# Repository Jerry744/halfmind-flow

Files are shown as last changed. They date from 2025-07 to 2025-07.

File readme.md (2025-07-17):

# Halfmind Flow

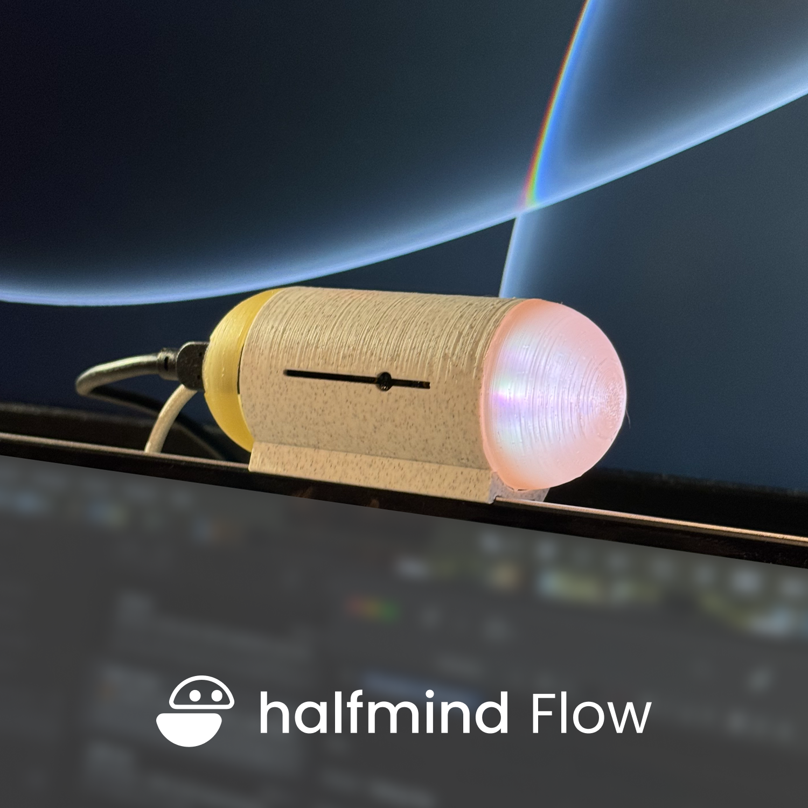
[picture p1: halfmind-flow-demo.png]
Halfmind Flow Demo

*Demo: Halfmind Flow system in action*

**Halfmind Flow** explores how radar sensing can support focus at work by detecting presence and breathing patterns to gently intervene when attention drifts.  
This project is part of my Master’s graduation project in the Integrated Product Design program at TU Delft.

## Overview

Halfmind Flow uses a 60 GHz millimeter-wave radar to sense whether someone is at their desk and monitors subtle breathing patterns. It calculates breathing rate variability (BRV) to infer focus and restlessness. When signs of distraction appear, ambient music and light adjust to help restore flow.

## Key Features

- Real-time presence and breathing detection via radar  
- Rule-based classification of work states using BRV  
- Generative music in Max/MSP to support focus  
- Ambient lighting driven by ESP32 with 7 LEDs to visualize breath depth or provide subtle nudges  
- Debug visualizations in PyQT5

## How It Works

1. Radar captures raw signals of presence and chest movements.  
2. Signal processing (FFT and filtering) extracts breathing features.  
3. A rule-based approach uses BRV to estimate current focus state.  
4. Music and lights adjust in response to support sustained attention.

## Tech Stack

- **Hardware:** Infineon BGT60TR13C radar module, ESP32 LED controller  
- **Software:** Python for signal processing, Max/MSP for music generation, PyQT5 for debugging  
- **Future Work:** Integration with Home Assistant and other ambient devices

## Roadmap

- [ ] Refine BRV detection and link to focus/anxiety states  
- [ ] Improve generative music logic  
- [ ] Expand lighting intervention scenarios  
- [ ] Test in real-world work setups and multi-user contexts

## Acknowledgements

- Radar signal processing inspired by work from Prof. Mohammad Alaee-Kerahroodi ([radarmimo GitHub](https://github.com/radarmimo/Download-Center)) and the Infineon Radar SDK.
- Generative music system references UndulaeMusic ([Patreon](https://www.patreon.com/UndulaeMusic)) and other open-source Max/MSP projects.
- Special thanks to my mentors and peers at TU Delft for their valuable guidance and feedback.

## License

This project is released under the XXX License. See [`LICENSE`](./LICENSE) for details.

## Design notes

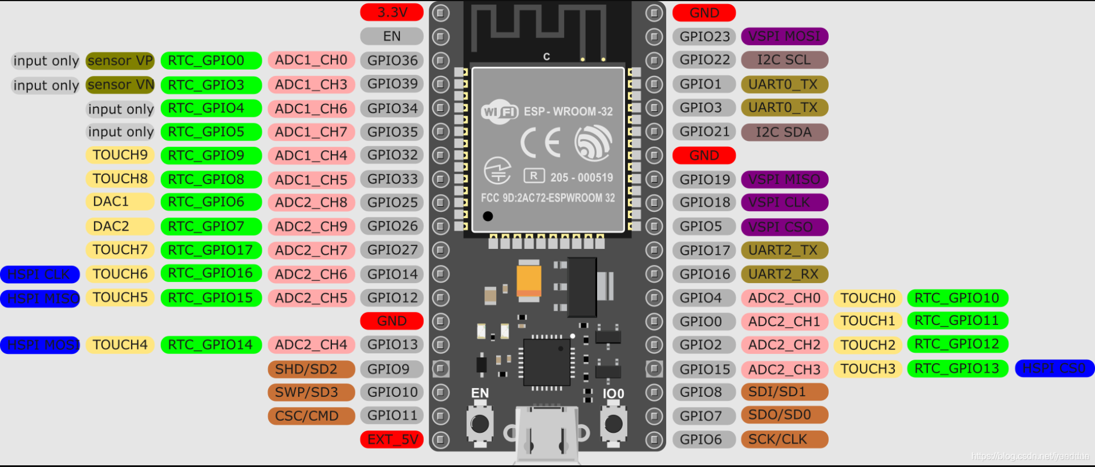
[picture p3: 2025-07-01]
arduino_esp32/esp32_layout.png

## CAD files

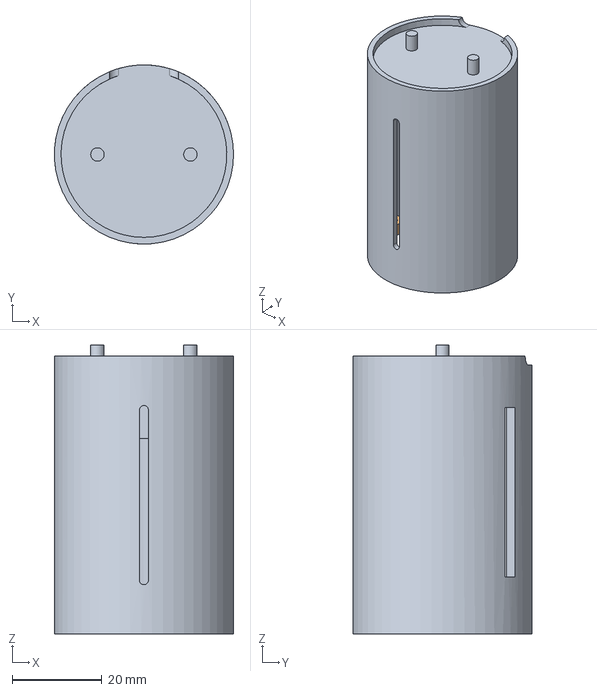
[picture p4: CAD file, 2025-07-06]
capsule/capsule_structure_assembly v11.step
40.0 x 40.0 x 64.5 mm

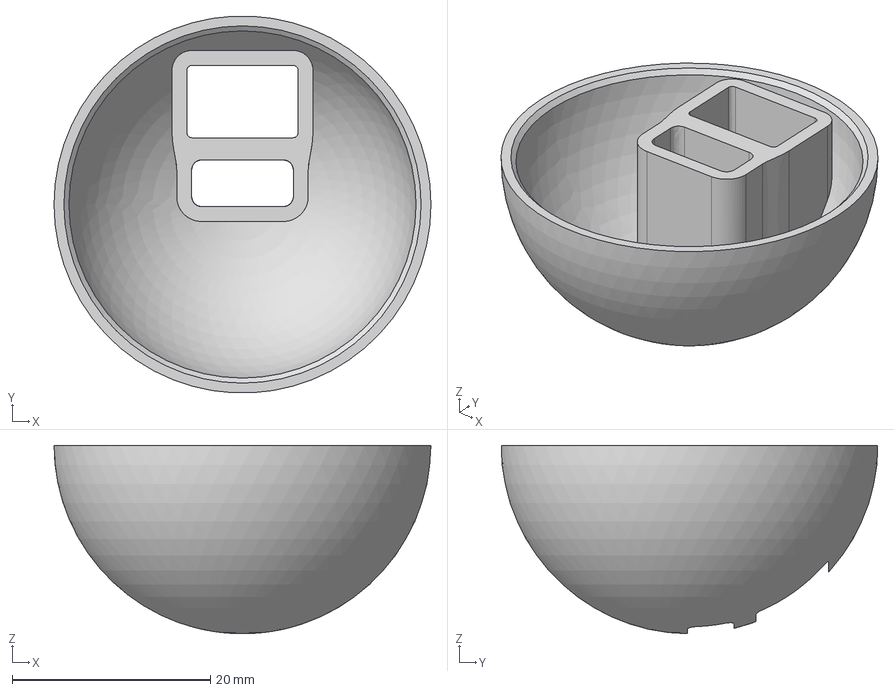
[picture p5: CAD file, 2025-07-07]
capsule/Hat_cable.step
38.0 x 37.9 x 19.0 mm

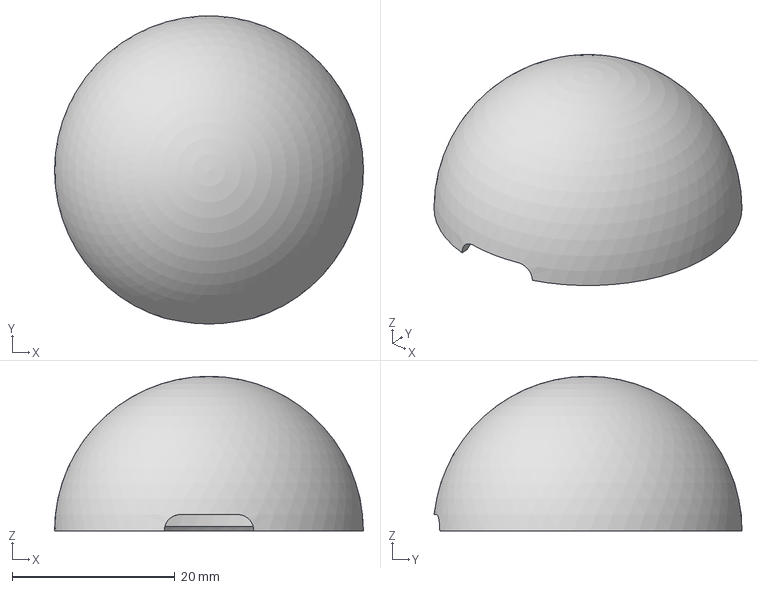
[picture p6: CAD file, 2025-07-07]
capsule/Hat_LED.step
38.0 x 37.9 x 19.0 mm

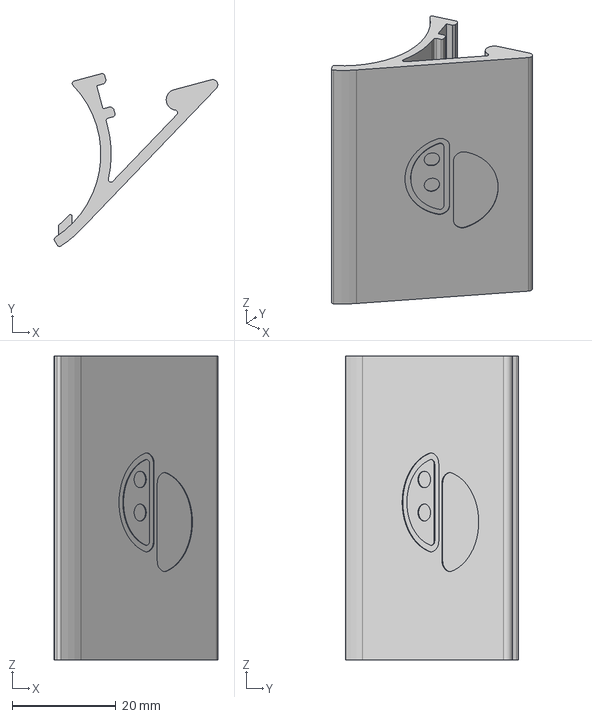
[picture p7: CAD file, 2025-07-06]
capsule/housing_stand.step
31.5 x 33.3 x 58.5 mm

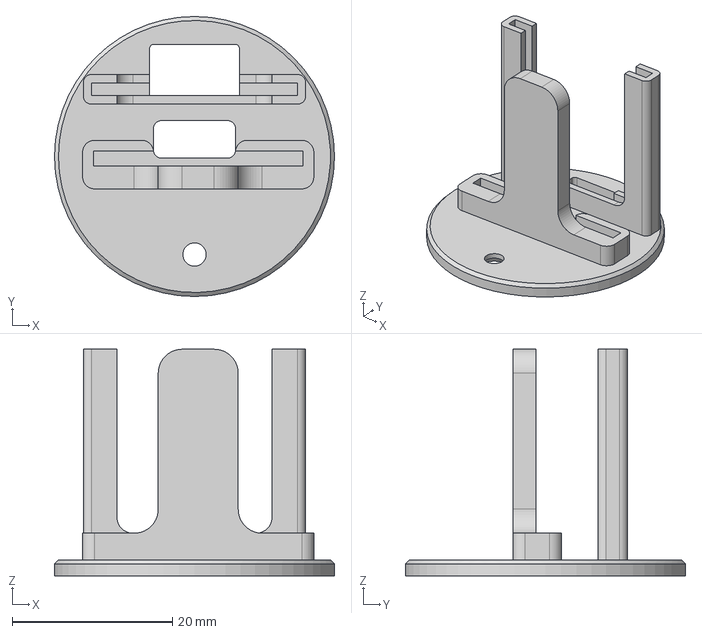
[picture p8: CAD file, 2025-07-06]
capsule/base v2.step
35.0 x 35.0 x 28.3 mm

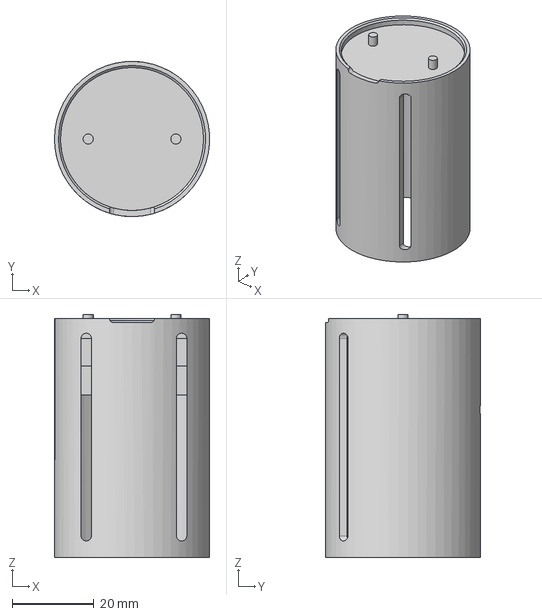
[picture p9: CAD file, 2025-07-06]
capsule/Shellv2.step
38.0 x 38.0 x 59.5 mm

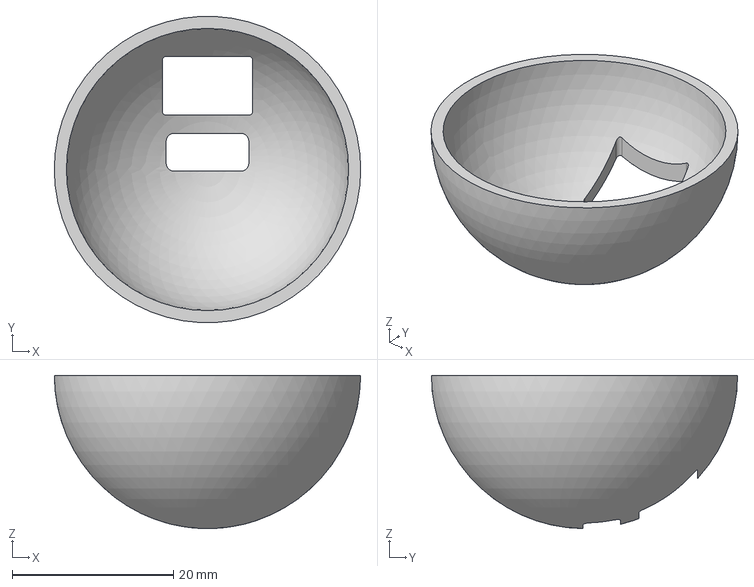
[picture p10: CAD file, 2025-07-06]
capsule/hat2.step
38.0 x 37.9 x 19.0 mm

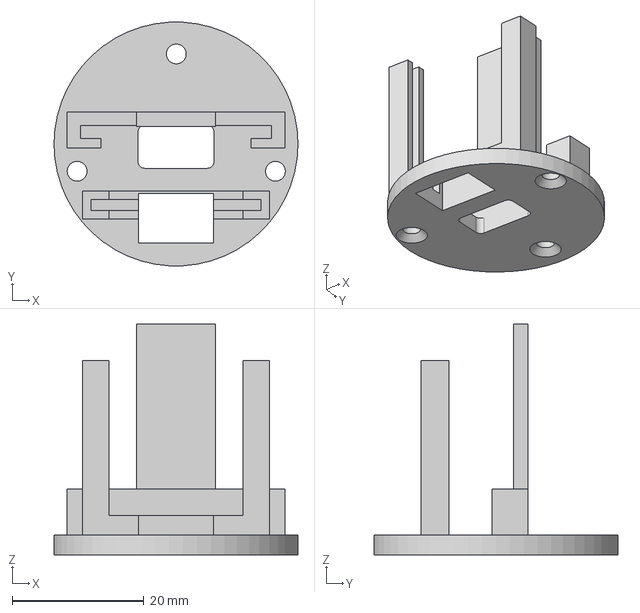
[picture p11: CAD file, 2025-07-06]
capsule/structure_base v5.step
37.0 x 36.9 x 35.0 mm

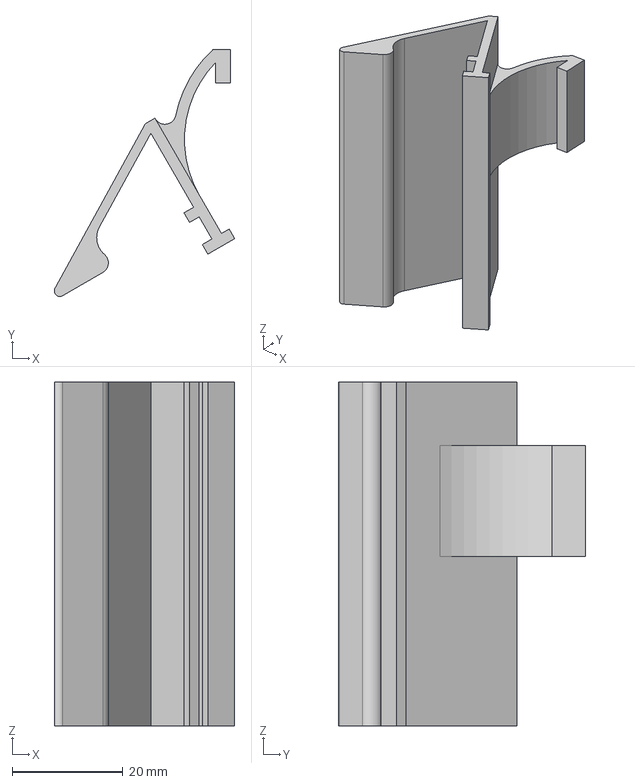
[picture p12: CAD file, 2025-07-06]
capsule/housing_holder.step
32.5 x 44.5 x 62.0 mm

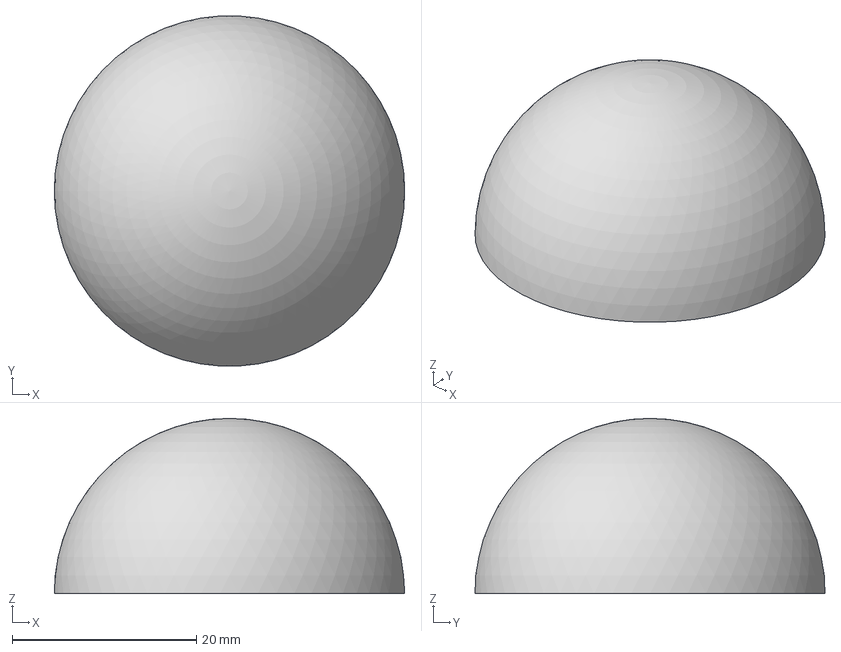
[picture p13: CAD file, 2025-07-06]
capsule/hat1.step
38.0 x 37.9 x 19.0 mm

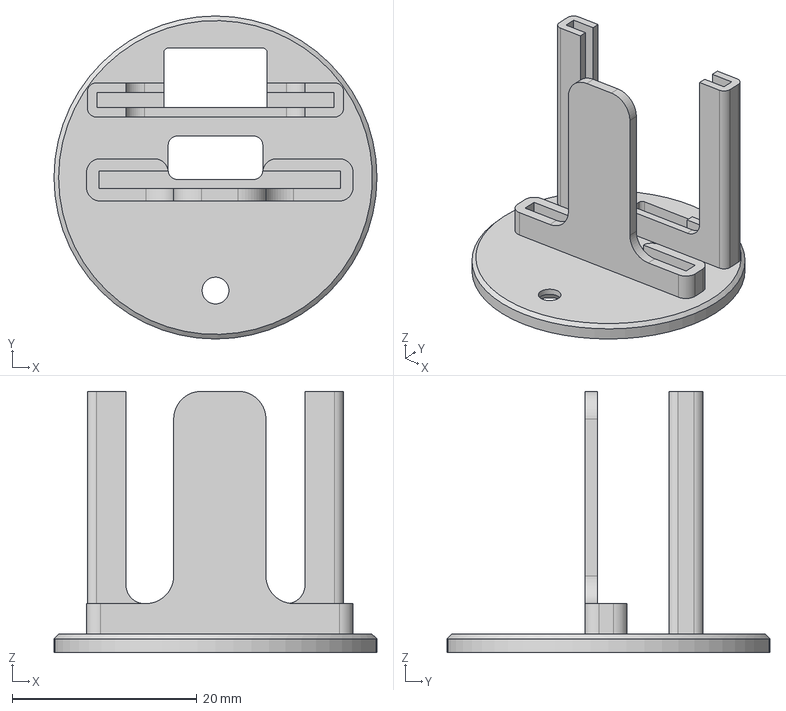
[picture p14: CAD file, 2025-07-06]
capsule/capsule-thinesp v2.step
35.0 x 35.0 x 28.3 mm

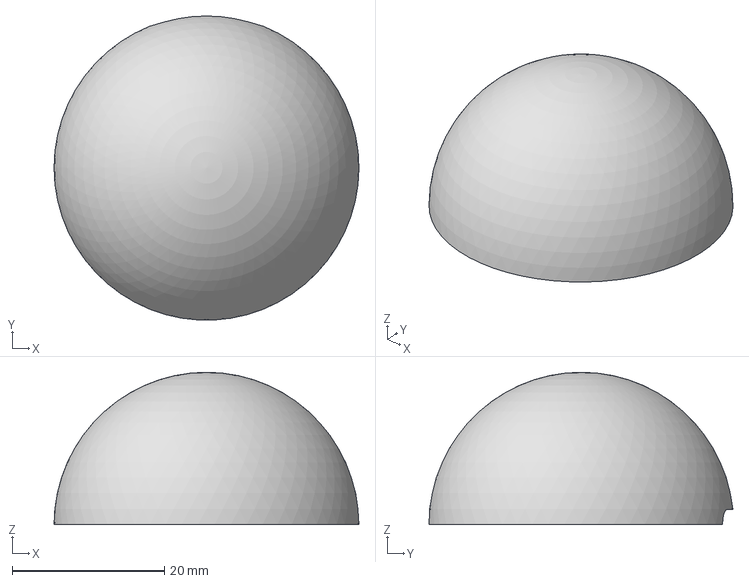
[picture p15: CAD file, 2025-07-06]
capsule/LED_Hat.step
40.0 x 39.9 x 20.0 mm

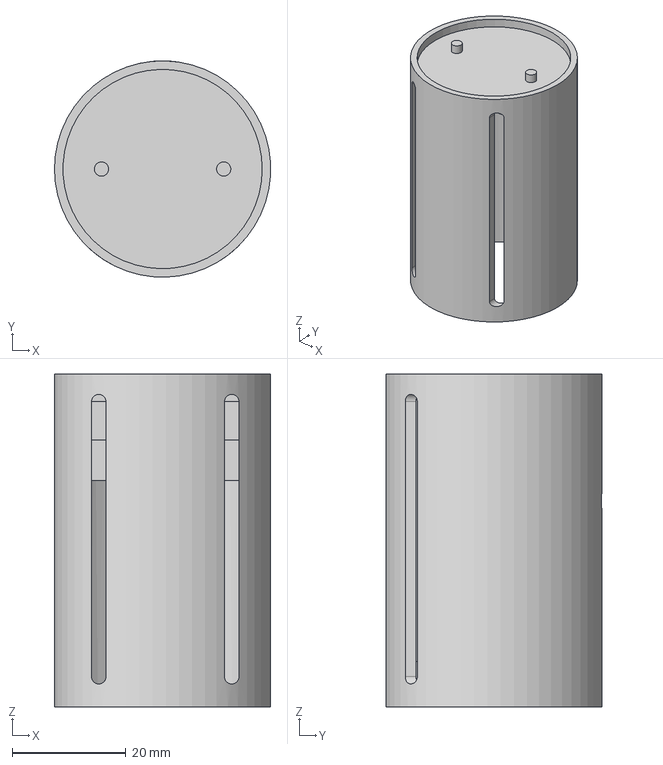
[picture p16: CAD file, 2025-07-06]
capsule/Shell.step
38.0 x 38.0 x 58.5 mm

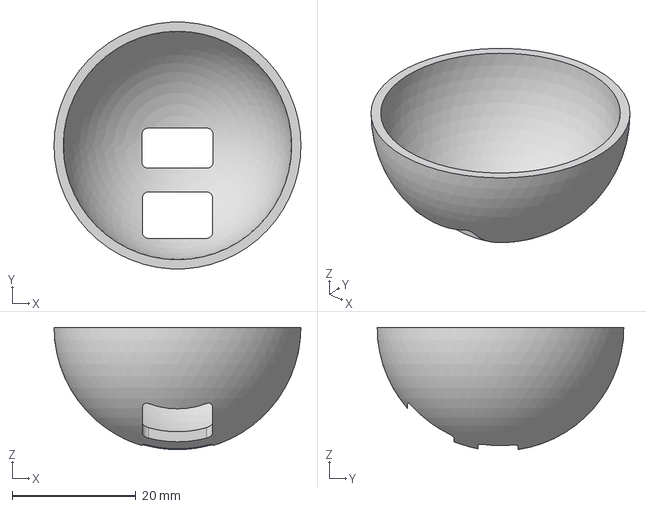
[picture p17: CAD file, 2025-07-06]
capsule/Cable_Hat.step
40.0 x 39.9 x 19.8 mm

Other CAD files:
capsule/Component4.step
capsule/structure_hat_v3 v1(Mirror).step
capsule/structure_v1_shell.stp
capsule/structure_hat_v3.stp
capsule/capsule_structure_assembly v6.step
capsule/capsule_structure_assembly v8.step
capsule/esp32.stp
capsule/led.stp
capsule/radar.stp
capsule/structure_base v2.step
capsule/structure_base v4.step
capsule/structure_base.step
capsule/structure_base_v2.stp
capsule/structure_base_v3.stp
capsule/structure_shell_v2.stp
capsule/structure_shell_v3.stp
capsule/structure_v1.stp
capsule/structure_v1_base.stp
capsule/structure_v1_hat.stp

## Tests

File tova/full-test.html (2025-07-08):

# T.O.V.A.

## Test of Variables of Attention

In the following task, you will be presented a series of stimuli consisting of a large white square with a small black square inside it.

On some trials, the small square will be near the top of the white square. These are target stimuli.

On other trials, the small square will be near the bottom. These are NOT target stimuli.

Continue to see the stimuli.

Continue

## Instructions

Your task is to decide if each stimulus is a target or non-target.

Press the space bar as quickly as you can whenever you see a target (top square).

Do nothing when you see a non-target (bottom square).

The task lasts approximately 23 minutes, so you must concentrate to perform well. First you will have 3 minutes to practice.

View Sample Stimuli

## 🎯 Target Stimulus Example

This is a Target stimulus.
When you see the small black square at the TOP of the white background,
press the SPACEBAR as quickly as possible.

Next: Non-Target Example

## ❌ Non-Target Stimulus Example

This is a Non-target stimulus.
When you see the small black square at the BOTTOM of the white background,
DO NOT PRESS ANY KEY - simply wait for the next stimulus.

Start Practice

ERROR

## Practice Complete

You have completed practice. The task will now begin.

Continue (Space)

## Practice Finished

You have successfully completed the practice session.

Press SPACEBAR to begin TOVA test.

Begin TOVA Test

# Thank you!

The test is complete.

Download Raw Data Download Summary Data

Start New Test Return to Main Page

### Subject Information

Subject Name:

Group ID:

Session ID:

Start Test

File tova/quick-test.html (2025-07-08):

Debug Info:

Phase: -

Block: -

Trial: -

Type: -

Last RT: -ms

Total Trials: -

Quick Controls:

Skip to Test Speed Up (100ms SOA) Normal Speed Show Stats Download Data

# T.O.V.A. Quick Test Mode

This is a debug/development version with shortened trials for testing.

Changes from full version:

- Practice: 6 trials (instead of 50)
- Each test block: 20 trials (instead of 162)
- Debug panel shows real-time info
- Quick controls for testing

Start Quick Test Full Test

# Quick Test Complete!

Download Data Restart

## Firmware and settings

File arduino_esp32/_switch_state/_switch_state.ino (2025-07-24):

#include <Adafruit_NeoPixel.h>
#include <WiFi.h>
#include <WiFiUdp.h>
#include <OSCMessage.h>

#define LED_PIN     12      // D12
#define NUM_LEDS    7
#define TOUCH_PIN   T0     // D4 (GPIO4, touch-capable)
#define BREATH_CYCLE_LENGTH 4.0  // Half breathing cycle in seconds

// WiFi settings
// const char* ssid = "TP-Link_CF74";
// const char* password = "81541027";

const char* ssid = "TP-Link_122D";
const char* password = "05997343";

const char* ssid_test = "TP-Link_DDFE";
const char* password_test = "10450215";
// OSC settings
WiFiUDP Udp;
const unsigned int localPort = 8888;  // Local port to listen on
const char* oscStatusAddress = "/status";        // OSC address for state control
const char* oscBreathingAddress = "/breathingrate"; // OSC address for breathing rate
const char* oscConfigAddress = "/config";            // OSC address for configuration
const char* oscAmplitudeAddress = "/amplitude";        // OSC address for amplitude control

// Designated IP address for OSC messages (change this to your sender's IP)
IPAddress designatedIP(192, 168, 31, 128);  // Change to your designated IP address
bool enableIPFiltering = false;  // Set to false to accept from any IP

// Dynamic breathing rate control
float currentBreathingRate = BREATH_CYCLE_LENGTH;  // Current breathing rate in seconds

// Global variables for breathing effect
float breathingBrightness = 0;
bool breathingIncreasing = true; // true = brightening, false = dimming
uint32_t breathingColor = 0;     // Set this to strip.Color(r, g, b) before use

// New global variable to store amplitude value
float breathAmplitude = 0; // 0-100, usually max 40

Adafruit_NeoPixel strip(NUM_LEDS, LED_PIN, NEO_GRB + NEO_KHZ800);

// 状态定义
enum {
  SETUP_TEST = 0,
  STATUS_0,   // nobody
  STATUS_1,   // user appear
  STATUS_2,   // user working
  STATUS_3,   // out of focus
  STATUS_4,   // time up
  STATUS_5    // user leave
};
int state = SETUP_TEST;
unsigned long stateStartTime = 0;
bool waitingForTimeout = false;
unsigned long lastTouchTime = 0;

// Helper function to connect to WiFi with timeout (returns true if connected, false if timeout)
bool connectToWiFiWithTimeout(const char* ssid, const char* password, unsigned long timeoutMs) {
  // Turn all LEDs yellow while connecting
  for (int i = 0; i < NUM_LEDS; i++) {
    strip.setPixelColor(i, strip.Color(30, 30, 0)); // Yellow
  }
  strip.show();

  WiFi.begin(ssid, password);
  Serial.print("Connecting to WiFi");
  unsigned long startAttemptTime = millis();
  while (WiFi.status() != WL_CONNECTED && millis() - startAttemptTime < timeoutMs) {
    delay(500);
    Serial.print(".");
  }
  Serial.println();

  bool connected = WiFi.status() == WL_CONNECTED;
  if (connected) {
    // Show green for 2 seconds
    for (int i = 0; i < NUM_LEDS; i++) {
      strip.setPixelColor(i, strip.Color(0, 30, 0)); // Green
    }
    strip.show();
    delay(2000);
  } else {
    // Show red for 2 seconds
    for (int i = 0; i < NUM_LEDS; i++) {
      strip.setPixelColor(i, strip.Color(30, 0, 0)); // Red
    }
    strip.show();
    delay(2000);
  }
  // Clear LEDs after feedback
  strip.clear();
  strip.show();
  return connected;
}

void setup() {
  Serial.begin(115200);
  Serial.println("Starting LED State Controller with OSC...");
  
  // Initialize LED strip
  strip.begin();
  strip.show();

  // Connect to WiFi with 30s timeout
  bool wifiConnected = connectToWiFiWithTimeout(ssid, password, 8000);
  if (!wifiConnected) {
    Serial.println("Primary WiFi failed. Trying backup WiFi...");
    wifiConnected = connectToWiFiWithTimeout(ssid_test, password_test, 8000);
  }
  if (wifiConnected) {
    Serial.print("Connected! IP address: ");
    Serial.println(WiFi.localIP());
    // Start UDP
    Udp.begin(localPort);
    Serial.print("OSC listening on port: ");
    Serial.println(localPort);
    Serial.println("OSC addresses: /status, /breathingrate, /config");
    // Display OSC security settings
    if (enableIPFiltering) {
      Serial.print("OSC IP filtering ENABLED - Only accepting messages from: ");
      Serial.println(designatedIP);
    } else {
      Serial.println("OSC IP filtering DISABLED - Accepting messages from any IP");
    }
  } else {
    Serial.println("WiFi connection failed after 8 seconds (both networks). Skipping network setup.");
  }
  
  state = STATUS_0;
  Serial.println("Setup complete. Entering STATUS_0 (nobody)");
}

void loop() {
  handleTouch();
  handleOSC();  // Handle incoming OSC messages

  unsigned long now = millis();
  switch (state) {
    case STATUS_0: // nobody, breathing orange
      orangeLow();
      break;
    case STATUS_1: // user appear, use amplitude-based orange breath
      orangeBreathWithAmplitude(breathAmplitude);
      break;
    case STATUS_2: // user working, breathing orange
      orangeBreath();
      break;
    case STATUS_3: // out of focus, blink once, then STATUS_2
      blinkOnce();
      break;
    case STATUS_4: // time up, rainbow, then STATUS_5
      rainbowCycle(5);
      state = STATUS_5;
      break;
    case STATUS_5: // user leave, blink red 5s, then STATUS_0
      redBlink5s();
      break;
  }
}

// Handle incoming OSC messages
void handleOSC() {
  OSCMessage msg;
  int size = Udp.parsePacket();
  
  if (size > 0) {
    // Get the sender's IP address
    IPAddress senderIP = Udp.remoteIP();
    
    // Check if IP filtering is enabled and if the sender is authorized
    if (enableIPFiltering && senderIP != designatedIP) {
      Serial.print("OSC message rejected from unauthorized IP: ");
      Serial.println(senderIP);
      
      // Clear the packet buffer
      while (size--) {
        Udp.read();
      }
      return;
    }
    
    // Process the message if IP is authorized or filtering is disabled
    while (size--) {
      msg.fill(Udp.read());
    }
    
    if (!msg.hasError()) {
      Serial.print("OSC message accepted from: ");
      Serial.println(senderIP);
      
      msg.route(oscStatusAddress, routeStatus);
      msg.route(oscBreathingAddress, routeBreathingRate);
      msg.route(oscConfigAddress, routeConfig);
      msg.route(oscAmplitudeAddress, routeAmplitude);
    } else {
      Serial.println("OSC message has errors");
    }
  }
}

// Route function for status OSC messages
void routeStatus(OSCMessage &msg, int addrOffset) {
  if (msg.isInt(0)) {
    int newState = msg.getInt(0);
    // Accept only 0-5 and map to STATUS_0..STATUS_5
    if (newState >= 0 && newState <= 5) {
      int oldState = state;
      state = STATUS_0 + newState;
      waitingForTimeout = false;
      Serial.print("OSC /status received! State changed from ");
      Serial.print(getStateName(oldState));
      Serial.print(" to ");
      Serial.println(getStateName(state));
    } else {
      Serial.print("Invalid state received via OSC /status: ");
      Serial.println(newState);
    }
  } else {
    Serial.println("OSC /status message received but not an integer");
  }
}

// Route function for breathing rate OSC messages
void routeBreathingRate(OSCMessage &msg, int addrOffset) {
  if (msg.isFloat(0)) {
    float newRate = msg.getFloat(0);
    
    // Validate breathing rate (0.1 to 20 seconds)
    if (newRate >= 0.1 && newRate <= 20.0) {
      float oldRate = currentBreathingRate;
      currentBreathingRate = newRate;
      
      Serial.print("OSC /breathingrate received! Breathing rate changed from ");
      Serial.print(oldRate);
      Serial.print("s to ");
      Serial.print(currentBreathingRate);
      Serial.println("s");
    } else {
      Serial.print("Invalid breathing rate received via OSC /breathingrate: ");
      Serial.println(newRate);
      Serial.println("Valid range: 0.1 to 20.0 seconds");
    }
  } else if (msg.isInt(0)) {
    // Also accept integer values
    int newRate = msg.getInt(0);
    
    if (newRate >= 1 && newRate <= 20) {
      float oldRate = currentBreathingRate;
      currentBreathingRate = (float)newRate;
      
      Serial.print("OSC /breathingrate received! Breathing rate changed from ");
      Serial.print(oldRate);
      Serial.print("s to ");
      Serial.print(currentBreathingRate);
      Serial.println("s");
    } else {
      Serial.print("Invalid breathing rate received via OSC /breathingrate: ");
      Serial.println(newRate);
      Serial.println("Valid range: 1 to 20 seconds");
    }
  } else {
    Serial.println("OSC /breathingrate message received but not a number");
  }
}

// Route function for configuration OSC messages
void routeConfig(OSCMessage &msg, int addrOffset) {
  // /config/ipfilter 0|1 - Enable/disable IP filtering
  // /config/setip a.b.c.d - Set designated IP address
  
  if (msg.match("/ipfilter", addrOffset)) {
    if (msg.isInt(0)) {
      bool newFiltering = msg.getInt(0) != 0;
      bool oldFiltering = enableIPFiltering;
      enableIPFiltering = newFiltering;
      
      Serial.print("OSC /config/ipfilter received! IP filtering changed from ");
      Serial.print(oldFiltering ? "ENABLED" : "DISABLED");
      Serial.print(" to ");
      Serial.println(enableIPFiltering ? "ENABLED" : "DISABLED");
    }
  } 
  else if (msg.match("/setip", addrOffset)) {
    if (msg.isString(0)) {
      char ipStr[16];
      msg.getString(0, ipStr, 16);
      
      // Parse IP address string (format: "192.168.1.100")
      IPAddress newIP;
      if (newIP.fromString(ipStr)) {
        IPAddress oldIP = designatedIP;
        designatedIP = newIP;
        
        Serial.print("OSC /config/setip received! Designated IP changed from ");
        Serial.print(oldIP);
        Serial.print(" to ");
        Serial.println(designatedIP);
      } else {
        Serial.print("Invalid IP address format received: ");
        Serial.println(ipStr);
      }
    }
  }
  else {
    Serial.println("Unknown config command received");
  }
}

// Route function for amplitude OSC messages
void routeAmplitude(OSCMessage &msg, int addrOffset) {
  if (msg.isFloat(0)) {
    breathAmplitude = msg.getFloat(0);
  } else if (msg.isInt(0)) {
    breathAmplitude = msg.getInt(0);
  } else {
    Serial.println("OSC /amplitude message received but not a number");
  }
  Serial.print("Received /amplitude: ");
  Serial.println(breathAmplitude);
}

// Helper function to get state name for debugging
String getStateName(int stateNum) {
  switch (stateNum) {
    case SETUP_TEST: return "SETUP_TEST";
    case STATUS_0: return "STATUS_0 (nobody)";
    case STATUS_1: return "STATUS_1 (working)";
    case STATUS_2: return "STATUS_2 (user working)";
    case STATUS_3: return "STATUS_3 (out of focus)";
    case STATUS_4: return "STATUS_4 (time up)";
    case STATUS_5: return "STATUS_5 (user leave)";
    default: return "UNKNOWN";
  }
}

// Touch: only one change per touch, regardless of touch time
void handleTouch() {
  static bool lastTouch = false;
  bool touch = touchRead(TOUCH_PIN) < 40; // Adjust threshold as needed
  unsigned long now = millis();
  if (touch && !lastTouch && now - lastTouchTime > 300) { // Debounce
    state = (state + 1) % 6 + 1; // Cycle STATUS_0~STATUS_5
    if (state > STATUS_5) state = STATUS_0;
    waitingForTimeout = false;
    lastTouchTime = now;
  }
  lastTouch = touch;
}

// Lighting functions

void orangeBreath() {
  // Set min and max brightness (0-255)
  const uint8_t minBrightness = 30;
  const uint8_t maxBrightness = 200;
  static float brightness = minBrightness;
  static bool increasing = true;
  // fadeAmount is based on breathing rate: higher rate = faster breathing
  float fadeAmount = (maxBrightness - minBrightness) / (currentBreathingRate * 50.0);

  // Calculate brightness step direction
  if (increasing) {
    brightness += fadeAmount;
    if (brightness >= maxBrightness) {
      brightness = maxBrightness;
      increasing = false;
    }
  } else {
    brightness -= fadeAmount;
    if (brightness <= minBrightness) {
      brightness = minBrightness;
      increasing = true;
    }
  }

  // Use constant color RGB(255,162,57), scale by brightness/255
  uint8_t r = (uint8_t)(255 * (brightness / 255.0));
  uint8_t g = (uint8_t)(162 * (brightness / 255.0));
  uint8_t b = (uint8_t)(57 * (brightness / 255.0));
  for (int i = 0; i < NUM_LEDS; i++) {
    strip.setPixelColor(i, strip.Color(r, g, b));
  }
  strip.show();
  delay(20);
}

void redSolid() {
  for (int i = 0; i < NUM_LEDS; i++) {
    strip.setPixelColor(i, strip.Color(255, 0, 0));
  }
  strip.show();
}

void orangeLow() {
  // 8% brightness of orange (255,162,57)
  float scale = 20.0 / 255.0; // 8% of 255 (20/255)
  uint8_t r = (uint8_t)(255 * scale);
  uint8_t g = (uint8_t)(162 * scale);
  uint8_t b = (uint8_t)(57 * scale);
  for (int i = 0; i < NUM_LEDS; i++) {
    strip.setPixelColor(i, strip.Color(r, g, b));
  }
  strip.show();
}

void blinkOnce() {
  static bool hasBlinked = false;
  static unsigned long blinkStart = 0;
  if (!hasBlinked) {
    for (int i = 0; i < NUM_LEDS; i++) {
      strip.setPixelColor(i, strip.Color(255, 255, 255));
    }
    strip.show();
    blinkStart = millis();
    hasBlinked = true;
  } else if (millis() - blinkStart >= 500) {
    strip.clear();
    strip.show();
    state = STATUS_2;
    hasBlinked = false;
  }
}

void rainbowCycle(uint8_t seconds) {
  uint32_t start = millis();
  while (millis() - start < seconds * 1000) {
    for (int j = 0; j < 256; j++) {
      for (int i = 0; i < NUM_LEDS; i++) {
        strip.setPixelColor(i, Wheel((i * 256 / NUM_LEDS + j) & 255));
      }
      strip.show();
      delay(20);
    }
  }
}

void redBlink5s() {
  static bool on = false;
  static unsigned long lastBlink = 0;
  static unsigned long startBlink = 0;
  if (!waitingForTimeout) {
    startBlink = millis();
    waitingForTimeout = true;
    on = false;
    lastBlink = 0;
  }
  if (millis() - lastBlink > 1000) {
    on = !on;
    for (int i = 0; i < NUM_LEDS; i++) {
      strip.setPixelColor(i, on ? strip.Color(255, 0, 0) : 0);
    }
    strip.show();
    lastBlink = millis();
  }
  if (millis() - startBlink >= 5000) {
    state = STATUS_0;
    waitingForTimeout = false;
  }
}

uint32_t Wheel(byte pos) {
  pos = 255 - pos;
  if (pos < 85) return strip.Color(255 - pos * 3, 0, pos * 3);
  else if (pos < 170) {
    pos -= 85;
    return strip.Color(0, pos * 3, 255 - pos * 3);
  } else {
    pos -= 170;
    return strip.Color(pos * 3, 255 - pos * 3, 0);
  }
}

void customBreathEffect(float minBrightness, float maxBrightness, float step) {
  // Update brightness
  if (breathingIncreasing) {
    breathingBrightness += step;
    if (breathingBrightness >= maxBrightness) {
      breathingBrightness = maxBrightness;
      breathingIncreasing = false;
    }
  } else {
    breathingBrightness -= step;
    if (breathingBrightness <= minBrightness) {
      breathingBrightness = minBrightness;
      breathingIncreasing = true;
    }
  }

  // Set all LEDs to the current color and brightness
  uint8_t r = (uint8_t)(((breathingColor >> 16) & 0xFF) * (breathingBrightness / 255.0));
  uint8_t g = (uint8_t)(((breathingColor >> 8) & 0xFF) * (breathingBrightness / 255.0));
  uint8_t b = (uint8_t)((breathingColor & 0xFF) * (breathingBrightness / 255.0));
  for (int i = 0; i < NUM_LEDS; i++) {
    strip.setPixelColor(i, strip.Color(r, g, b));
  }
  strip.show();
  delay(10); // Adjust for smoother/faster effect
}

// Helper to set all LEDs to a color with brightness scaling (0-255)
void setAllLedsColorWithBrightness(uint8_t r, uint8_t g, uint8_t b, uint8_t brightness) {
  float scale = brightness / 255.0;
  uint8_t r_scaled = (uint8_t)(r * scale);
  uint8_t g_scaled = (uint8_t)(g * scale);
  uint8_t b_scaled = (uint8_t)(b * scale);
  for (int i = 0; i < NUM_LEDS; i++) {
    strip.setPixelColor(i, strip.Color(r_scaled, g_scaled, b_scaled));
  }
  strip.show();
}

// Function to set orange LED brightness based on amplitude
void orangeBreathWithAmplitude(float amplitude) {
  // Clamp amplitude to 0-100
  // if (amplitude < 0) amplitude = 0;
  if (amplitude > 40) amplitude = 40;
  // Map amplitude (0-100, usually max 40) to brightness (20%-60%)
  float base = 0.6; // 60%
  float scale = 1; // 40% range
  float brightness = base - (amplitude / 100.0) * scale; // 0.2 to 0.6 (reversed)
  // Amplitude < 0 is for debugging, make sure brightness is not negative
  if (brightness < 0) brightness = 0;
  uint8_t led_brightness = (uint8_t)(brightness * 255);
  setAllLedsColorWithBrightness(255, 162, 57, led_brightness);
}

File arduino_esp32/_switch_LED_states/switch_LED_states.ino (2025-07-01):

#include <WiFi.h>
#include <WiFiUdp.h>
#include <Adafruit_NeoPixel.h>
#include <OSCMessage.h>

#define LED_PIN     5
#define NUM_LEDS    7
#define TOUCH_PIN   T0  // GPIO4 - Single touch pin for mode switching

Adafruit_NeoPixel strip(NUM_LEDS, LED_PIN, NEO_GRB + NEO_KHZ800);

// WiFi & OSC
const char* ssid = "YOUR_SSID";
const char* password = "YOUR_PASSWORD";
WiFiUDP Udp;
const int localPort = 8000;

// State control
int state = -1;  // Start with setup test (-1)
unsigned long stateStartTime = 0;
bool waitingForTimeout = false;
unsigned long lastTouchTrigger = 0;
bool setupComplete = false;

void setup() {
  Serial.begin(115200);
  strip.begin();
  strip.show();
  
  // Setup test: turn on green light for 2 seconds
  for (int i = 0; i < NUM_LEDS; i++) {
    strip.setPixelColor(i, strip.Color(0, 255, 0)); // Green
  }
  strip.show();
  delay(2000);
  
  // Turn off all lights
  strip.clear();
  strip.show();
  
  setupComplete = true;
  state = 0; // Start with status 0 (nobody - breathing orange)
  
  touchAttachInterrupt(TOUCH_PIN, onTouch, 40);

  WiFi.begin(ssid, password);
  while (WiFi.status() != WL_CONNECTED) {
    delay(500);
    Serial.print(".");
  }
  Serial.println("\nWiFi connected");
  Udp.begin(localPort);
}

void loop() {
  if (!setupComplete) return;
  
  checkOSC();

  unsigned long now = millis();
  
  switch (state) {
    case 0: // Status 0: nobody - breathing orange light
      orangeBreath();
      break;
      
    case 1: // Status 1: user appear - red light for 5 seconds
      redSolid();
      if (!waitingForTimeout) {
        stateStartTime = now;
        waitingForTimeout = true;
      } else if (now - stateStartTime >= 5000) {
        state = 2; // Move to status 2 (user working)
        waitingForTimeout = false;
      }
      break;
      
    case 2: // Status 2: user working - orange light 20% brightness
      orangeLowBrightness();
      break;
      
    case 3: // Status 3: out of focus - blink once
      blinkOnce();
      break;
      
    case 4: // Status 4: time up - rainbow strip
      rainbowCycle(5);
      state = 0; // Return to status 0
      break;
      
    case 5: // Status 5: user leave - blinking red for 5 seconds
      redBlink();
      if (!waitingForTimeout) {
        stateStartTime = now;
        waitingForTimeout = true;
      } else if (now - stateStartTime >= 5000) {
        state = 0; // Return to status 0
        waitingForTimeout = false;
      }
      break;
  }
}

// OSC receive handling
void checkOSC() {
  int size = Udp.parsePacket();
  if (size > 0) {
    OSCMessage msg;
    while (size--) {
      msg.fill(Udp.read());
    }
    if (!msg.hasError()) {
      msg.route("/state", handleState);
    }
  }
}

void handleState(OSCMessage &msg, int addrOffset) {
  if (msg.isInt(0)) {
    int newState = msg.getInt(0);
    if (newState >= 0 && newState <= 5) {
      state = newState;
      waitingForTimeout = false;
      Serial.print("OSC State changed to ");
      Serial.println(state);
    }
  }
}

// Lighting functions
void orangeBreath() {
  static int brightness = 0;
  static int fadeAmount = 5;
  for (int i = 0; i < NUM_LEDS; i++) {
    strip.setPixelColor(i, strip.Color(255 * brightness / 255, 80 * brightness / 255, 0));
  }
  strip.show();
  brightness += fadeAmount;
  if (brightness <= 0 || brightness >= 255) fadeAmount = -fadeAmount;
  delay(20);
}

void redSolid() {
  for (int i = 0; i < NUM_LEDS; i++) {
    strip.setPixelColor(i, strip.Color(255, 0, 0));
  }
  strip.show();
}

void orangeLowBrightness() {
  // 20% brightness orange
  for (int i = 0; i < NUM_LEDS; i++) {
    strip.setPixelColor(i, strip.Color(255 * 0.2, 80 * 0.2, 0));
  }
  strip.show();
}

void blinkOnce() {
  static bool hasBlinked = false;
  static unsigned long blinkStartTime = 0;
  
  if (!hasBlinked) {
    // Turn on all LEDs
    for (int i = 0; i < NUM_LEDS; i++) {
      strip.setPixelColor(i, strip.Color(255, 255, 255)); // White blink
    }
    strip.show();
    blinkStartTime = millis();
    hasBlinked = true;
  } else if (millis() - blinkStartTime >= 500) { // Blink for 500ms
    // Turn off all LEDs
    strip.clear();
    strip.show();
    state = 2; // Return to status 2 (user working)
    hasBlinked = false;
  }
}

void rainbowCycle(uint8_t seconds) {
  uint32_t start = millis();
  while (millis() - start < seconds * 1000) {
    for (int j = 0; j < 256; j++) {
      for (int i = 0; i < NUM_LEDS; i++) {
        strip.setPixelColor(i, Wheel((i * 256 / NUM_LEDS + j) & 255));
      }
      strip.show();
      delay(20);
    }
  }
}

void redBlink() {
  static bool on = false;
  static unsigned long lastBlink = 0;
  if (millis() - lastBlink > 1000) { // 1 second interval
    on = !on;
    for (int i = 0; i < NUM_LEDS; i++) {
      strip.setPixelColor(i, on ? strip.Color(255, 0, 0) : 0);
    }
    strip.show();
    lastBlink = millis();
  }
}

uint32_t Wheel(byte pos) {
  pos = 255 - pos;
  if (pos < 85) return strip.Color(255 - pos * 3, 0, pos * 3);
  else if (pos < 170) {
    pos -= 85;
    return strip.Color(0, pos * 3, 255 - pos * 3);
  } else {
    pos -= 170;
    return strip.Color(pos * 3, 255 - pos * 3, 0);
  }
}

// Touch function - each touch changes status once
void onTouch() {
  if (millis() - lastTouchTrigger > 300) { // Debounce
    state = (state + 1) % 6; // Cycle through states 0-5
    waitingForTimeout = false;
    Serial.println("Touch -> State: " + String(state));
    lastTouchTrigger = millis();
  }
}

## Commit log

2025-07-01 Initial commit
    Add files
    [esp32.stp, led.stp, radar.stp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]
2025-07-01 add radar driver for macOS
2025-07-02 optimize osc control
    bug fix of wifi
    ready for remote control by radar board
    [_switch_state.ino]
2025-07-03 Add structure file + fix radar range
    [capsule_structure_assembly v6.step, structure_base v2.step]
2025-07-03 add human existence check from radar
    [structure_base.step, structure_hat_v3 v1(Mirror).step]
2025-07-06 Update model
    [Shellv2.step, base v2.step, housing_stand.step]
2025-07-07 Update work timer, & fix model
    [Hat_LED.step, Hat_cable.step]
2025-07-07 Update Software & Hardware Integration
    - Connect radar python script to ESP32 lighting interventions.
    - Bug fixes
    - Set ESP32 IP Address to 192.168.31.62 in LAN
    [_switch_state.ino]
2025-07-08 Bug fix for hardware integration
    [_switch_state.ino]
2025-07-11 Update radar logic
    Add threading management to main program。
2025-07-17 Add breathing rate baseline and intervention logic
    Introduced global variables for breathing rate baseline calculation and intervention control in radar processing. Updated presence detection threshold and added logic to trigger and stop anxiety inte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
    Also adjusted brightness mapping in orangeBreathWithAmplitude in Arduino code (brighter for inhaling, dimmer for exhaling).
2025-07-24 Update WiFi, radar logging, and attention scoring
    Switched WiFi credentials and added backup network logic in ESP32 code. Enhanced radar processing with CSV logging, improved intervention timing, and adjusted detection thresholds. Refactored attention score calculation to use correct z-score direction and updated dataset keys for response time. Changed analysis folder path in main script.
    [_switch_state.ino]
